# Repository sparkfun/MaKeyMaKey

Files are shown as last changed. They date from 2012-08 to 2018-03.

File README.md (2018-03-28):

**Note: Retired Product**
===========

This product has been retired from our catalog and is no longer for sale. This page is made available for those looking for datasheets and the simply curious. For the latest version of the board manufactured by JoyLabz, check out the [Makey Makey Classic by JoyLabz](https://www.sparkfun.com/products/14478).

---

MaKey MaKey
===========

[MaKey MaKey  
*MaKey MaKey - Standard Kit (WIG-11511)*](https://www.sparkfun.com/products/11511)

Using the MaKey MaKey you can *make* anything into a *key* (get it?) just by connecting a few alligator clips. The MaKey MaKey is an invention kit that tricks your computer into thinking that almost anything is a keyboard. This allows you to hook up all kinds of fun things as an input.

The MaKey MaKey uses high resistance switching to detect when you've made a connection even through materials that aren't very conductive (like leaves, pasta or people). This technique attracts noise on the input, so a moving window averager is used to lowpass the noise. The on-board ATMega32u4 communicates with your computer using the Human Interface Device (HID) protocol which means that it can act like a keyboard or mouse.

Repository Contents
-------------------
* **/Firmware** - Example firmware files
* **/Hardware** - All Eagle design files (.brd, .sch)
* **/Production** - Test bed files and production panel files

Documentation
--------------
* **[Makey Makey Quickstart Guide](https://learn.sparkfun.com/tutorials/makey-makey-quickstart-guide)** - Basic hookup guide for the Makey Makey.
* **[Makey Makey Advanced Guide](https://learn.sparkfun.com/tutorials/makey-makey-advanced-guide)** - Advanced hookup guide for the Makey Makey.

Product Versions
----------------

**[WIG-11511 (Retired)](https://www.sparkfun.com/products/11511) - Standard kit, OEM packaging**  
The standard kit includes the MaKey MaKey HID board, alligator clips, jumper wires, and a Mini-USB cable in OEM packaging.

**[WIG-11519 (Retired)](https://www.sparkfun.com/products/11519) - Deluxe kit, OEM packaging**  
The deluxe kit includes everything found in the standard kit along with an additional pack of alligator clips and a roll of copper wire (all in OEM packaging).

**[RTL-11437 (Retired)](https://www.sparkfun.com/products/11437) - Standard kit, retail packaging**  
This kit contains everything found in the standard kit and comes in retail-ready plastic packaging.

License Information
-------------------
The hardware is released under [Creative Commons ShareAlike 4.0 International](https://creativecommons.org/licenses/by-sa/4.0/).
The code is beerware; if you see me (or any other SparkFun employee) at the local, and you've found our code helpful, please buy us a round!

Distributed as-is; no warranty is given.

The MaKey MaKey is a collaboration with Jay Silver and Eric Rosenbaum. You can find more information about them [here](http://www.makeymakey.com/).

Makey Makey is a registered trademark of JoyLabz LLC.

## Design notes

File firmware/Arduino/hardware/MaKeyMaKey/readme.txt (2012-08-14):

------------------------------------------------------
| MaKey MaKey Arduino Addon (updated August 9, 2012) |
------------------------------------------------------

This Arduino addon for the MaKey MaKey creates an Arduino Board menu option for the MaKey MaKey.

-------------------------------------------------
|         Installing the Arduino Addon          |
-------------------------------------------------

To install this addon, unzip the "MaKeyMaKey" folder into a "hardware" folder withing your Arduino sketchbook. If you don't know where your sketchbook is located, you can find it's location by going to File > Preferences within Arduino.

For Windows XP users, the sketchbook is usually located in your "My Documents/Arduino" directory. So once unzipped, this readme should reside in "My Documents/Arduino/hardware/ProMicro". Windows 7, by default, is something like: C:\Users\<user name>\Arduino\hardware\ProMicro.

Once unzipped, close any Arduino windows and reopen. The following board should be listed in the Tools > Board menu now:
MaKey MaKey

Important: Though the new bootloader is Leonardo-compatible, DO NOT select "Arduino Leonardo" from the Tools > Board menu before uploading code to the MaKey MaKey. Because the MaKey MaKey runs at 8MHz, the sketch uploaded to the board must be configured for that same speed.

-------------------------------------------------
|     Installing the Drivers (Windows only)     |
-------------------------------------------------
Windows users will need to install drivers the first time you connect the MaKey MaKey. Usually a New Hardware Wizard will pop up, you'll need to direct it to the included "Drivers" folder. The driver is "MaKey MaKey.inf".

The included driver should work for MaKey MaKey's with the Sparkfun VID/PID: 0x1B4F/0x2B74 (bootloader) and 0x2B75 (sketch)).

-------------------------------------------------
|            What files are included?           |
-------------------------------------------------

This addon should work with no need to modify files. If you're curious what we've done to the default Arduino files though, read on...

* bootloaders/caterina: This is a slightly modified version of the Caterina bootloader, which is used in the Arduino Leonardo. Defines were modified so the VID and PID were set to SparkFun-specific values (VID: 0x1B4F, PIDs: 0xF100/F101 [get it?!]). To compile this, you'll need to download LUFA, and point the makefile to that directory.

To compile the bootloader for a MaKey MaKey, you must first set F_CPU and PID near the top of the makefile. F_CPU should be 16000000.  PID should be 2B74.

This directory also includes Caterina-makeymakey.hex which is the compiled images of the MaKey MaKey's bootloader. It won't be deleted after running a 'make clean'.

* cores/arduino: This is a mostly unchanged listing of all the core files required by the MaKey MaKey to compile under Arduino. The files with changes are:
	USBCore.cpp: added conditional statement for seting PLLCSR.
	
* variants/makeymakey: This is mostly identical to the Leonardo pins_arduino.h. There is a slight change to the RX and TX LED macros, because the LEDs are biased towards ground, instead of VCC, we had to flop those macros.

* boards.txt: This file is what Arduino looks at when populating its Tools > Board menu.
The "MaKey MaKey" will be added to the Tools > Board menu.

This also defines a few variables such as clock frequency, USB VID and PID, fuses, and bootloader location.

-------------------------------------------------
|         Questions, Comments, Concerns?        |
-------------------------------------------------

Please let us know if this gives you any problems. You can contact our tech support team (techsupport@sparkfun.com), or post a comment on the product page (or even contact me by email, I'd be happy to help) and we'll try to get back to you as quickly as possible.

Have fun!
-Jim (jim at sparkfun.com)

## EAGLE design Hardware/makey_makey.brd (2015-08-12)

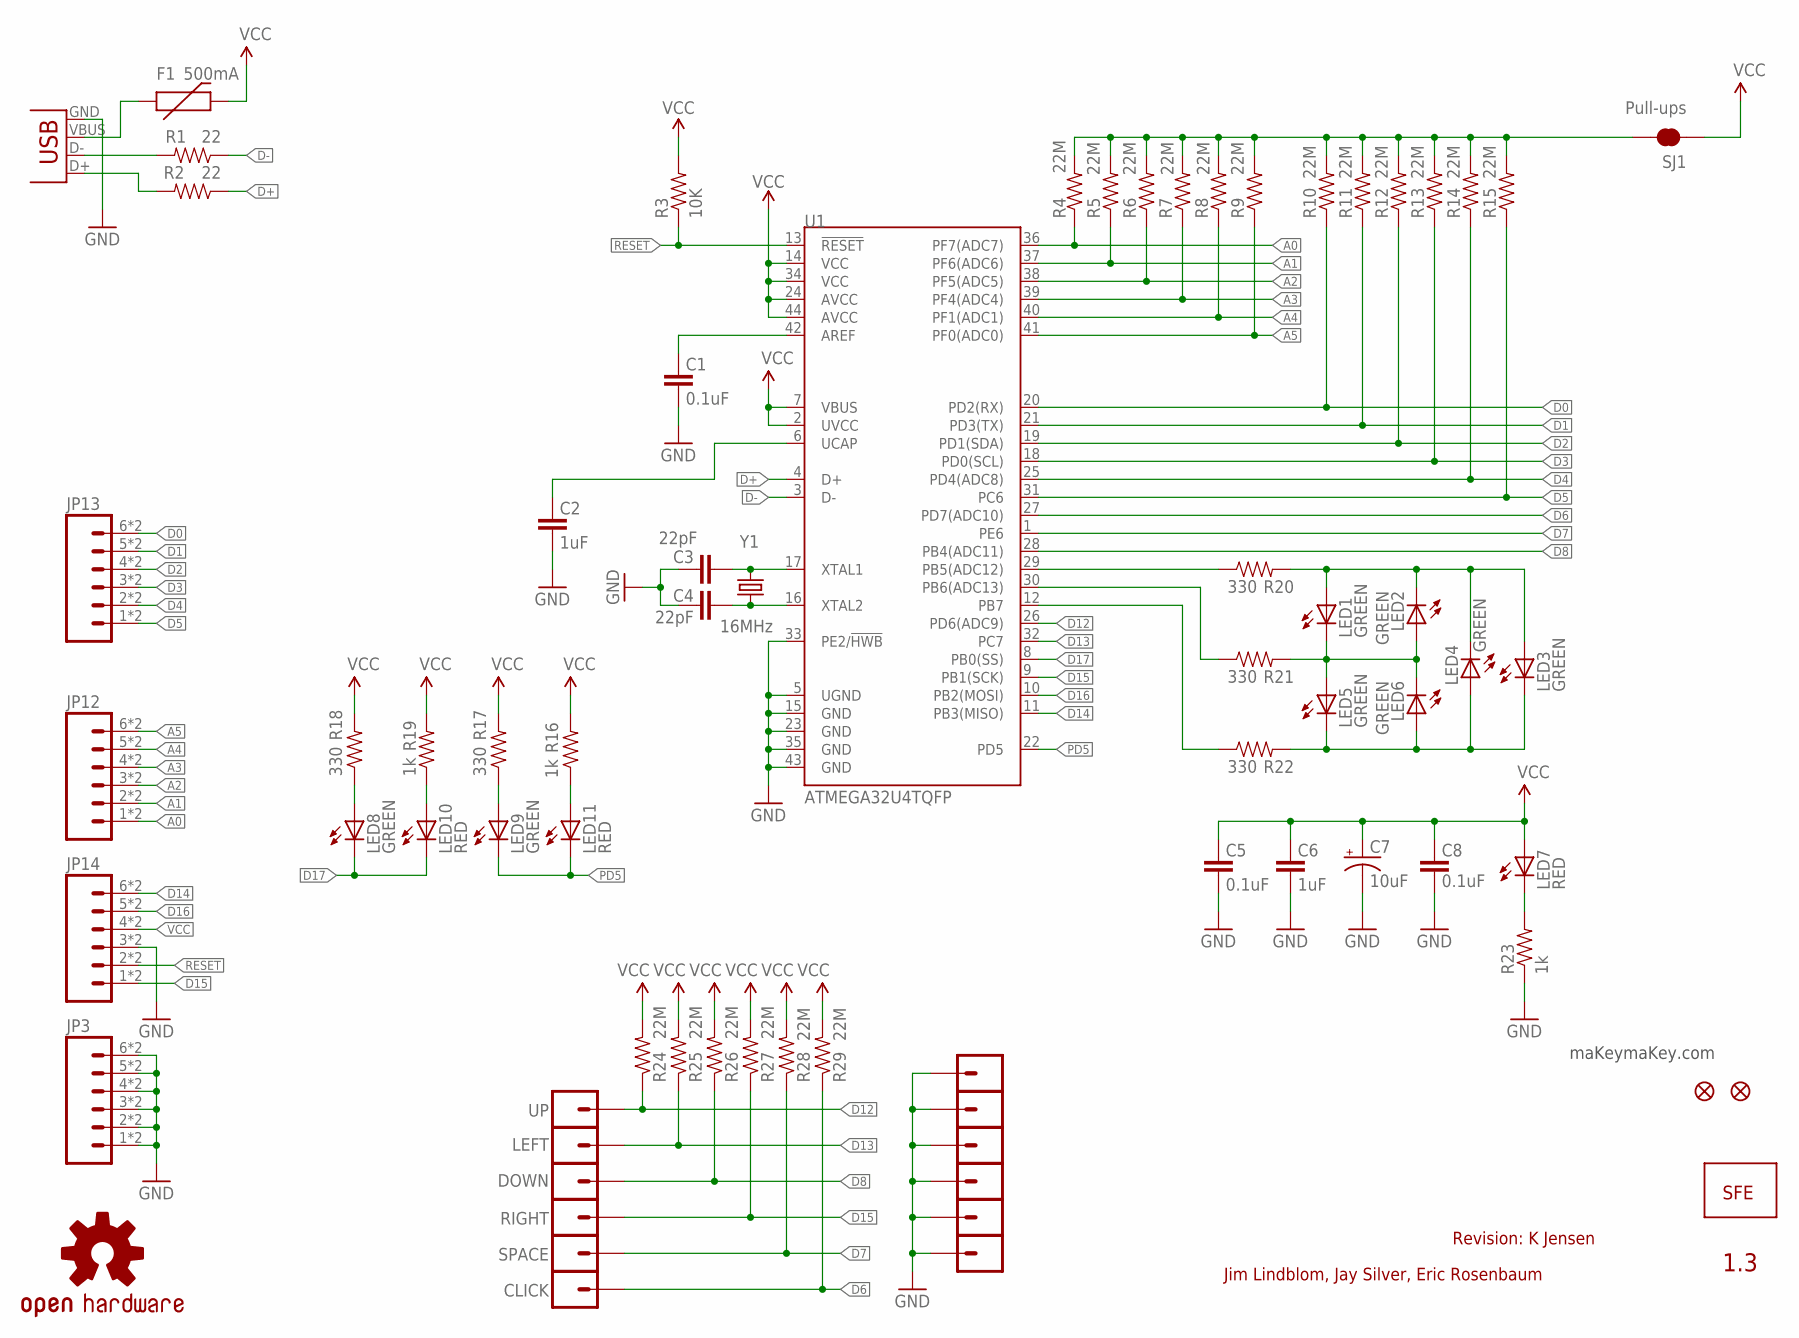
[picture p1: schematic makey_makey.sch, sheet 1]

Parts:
C1, C5, C8: 0.1uF; 0603-CAP
C2, C6: 1uF; 0603-CAP
C3, C4: 22pF; 0603-CAP
C7: 10uF; EIA3216
CLICK: M01ALLIGATOR-3MM; 1X01_ALLIGATOR_3MM
DOWN: M01ALLIGATOR-3MM; 1X01_ALLIGATOR_3MM
F1: 500mA; PTC-1206-WIDE
JP1, JP2: FIDUCIALUFIDUCIAL; MICRO-FIDUCIAL
JP3, JP12, JP13, JP14: M06SMD-STRAIGHT-COMBO; 1X06_SMD_STRAIGHT_COMBO
JP5, JP6, JP7, JP8, JP10, JP11: M01ALLIGATOR-3MM; 1X01_ALLIGATOR_3MM
JP9: LOGO-SFENEW; SFE-NEW-WEBLOGO
LED1, LED2, LED3, LED4, LED5, LED6: GREEN; LED-1206-BOTTOM
LED7, LED10, LED11: RED; LED-0603
LED8, LED9: GREEN; LED-0603
LEFT: M01ALLIGATOR-3MM; 1X01_ALLIGATOR_3MM
R1, R2: 22; 0603-RES
R3: 10K; 0603-RES
R4, R5, R6, R7, R8, R9, R10, R11, R12, R13, R14, R15, R24, R25, R26, R27, R28, R29: 22M; 0603-RES
R16, R19, R23: 1k; 0603-RES
R17, R18, R20, R21, R22: 330; 0603-RES
RIGHT: M01ALLIGATOR-3MM; 1X01_ALLIGATOR_3MM
SJ1: Pull-ups; SJ_2S-TRACE
SPACE: M01ALLIGATOR-3MM; 1X01_ALLIGATOR_3MM
U1: ATMEGA32U4TQFP; TQFP44
U$1: OSHW-LOGOM; OSHW-LOGO-M
UP: M01ALLIGATOR-3MM; 1X01_ALLIGATOR_3MM
X1: USBSMD; USB-MINIB
Y1: 16MHz; CRYSTAL-SMD-5X3

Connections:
A0: JP12.1, JP12.1-2 (1), R4.1, U1.36 (PF7(ADC7))
A1: JP12.2, JP12.2-2 (2), R5.1, U1.37 (PF6(ADC6))
A2: JP12.3, JP12.3-2 (3), R6.1, U1.38 (PF5(ADC5))
A3: JP12.4, JP12.4-2 (4), R7.1, U1.39 (PF4(ADC4))
A4: JP12.5, JP12.5-2 (5), R8.1, U1.40 (PF1(ADC1))
A5: JP12.6, JP12.6-2 (6), R9.1, U1.41 (PF0(ADC0))
AREF: C1.2, U1.42 (AREF)
D0: JP13.6, JP13.6-2 (6), R10.1, U1.20 (PD2(RX))
D1: JP13.5, JP13.5-2 (5), R11.1, U1.21 (PD3(TX))
D2: JP13.4, JP13.4-2 (4), R12.1, U1.19 (PD1(SDA))
D3: JP13.3, JP13.3-2 (3), R13.1, U1.18 (PD0(SCL))
D4: JP13.2, JP13.2-2 (2), R14.1, U1.25 (PD4(ADC8))
D5: JP13.1, JP13.1-2 (1), R15.1, U1.31 (PC6)
D6: CLICK.1@0, CLICK.1@2, R29.1, U1.27 (PD7(ADC10))
D7: R28.1, SPACE.1@0, SPACE.1@2, U1.1 (PE6)
D8: DOWN.1@0, DOWN.1@2, R26.1, U1.28 (PB4(ADC11))
D9: R20.1, U1.29 (PB5(ADC12))
D10: R21.1, U1.30 (PB6(ADC13))
D11: R22.1, U1.12 (PB7)
D12: R24.1, U1.26 (PD6(ADC9)), UP.1@0, UP.1@2
D13: LEFT.1@0, LEFT.1@2, R25.1, U1.32 (PC7)
D14: JP14.6, JP14.6-2 (6), U1.11 (PB3(MISO))
D15: JP14.1, JP14.1-2 (1), R27.1, RIGHT.1@0, RIGHT.1@2, U1.9 (PB1(SCK))
D16: JP14.5, JP14.5-2 (5), U1.10 (PB2(MOSI))
D17: LED8.C, LED10.C, U1.8 (PB0(SS))
D+: R2.1, U1.4 (D+)
D-: R1.1, U1.3 (D-)
GND: C1.1, C2.1, C3.2, C4.2, C5.1, C6.1, C7.C (-), C8.1, JP3.1, JP3.1-2 (1), JP3.2, JP3.2-2 (2), JP3.3, JP3.3-2 (3), JP3.4, JP3.4-2 (4), JP3.5, JP3.5-2 (5), JP3.6, JP3.6-2 (6), JP5.1@0, JP5.1@2, JP6.1@0, JP6.1@2, JP7.1@0, JP7.1@2, JP8.1@0, JP8.1@2, JP10.1@0, JP10.1@2, JP11.1@0, JP11.1@2, JP14.3, JP14.3-2 (3), R23.1, U1.5 (UGND), U1.15 (GND), U1.23 (GND), U1.33 (PE2/!HWB), U1.35 (GND), U1.43 (GND), X1.GND
unnamed: C4.1, U1.16 (XTAL2), Y1.1
unnamed: C3.1, U1.17 (XTAL1), Y1.3 (2)
unnamed: LED8.A, R18.1
unnamed: C2.2, U1.6 (UCAP)
unnamed: F1.1, X1.VBUS
unnamed: R1.2, X1.D-
unnamed: LED7.C, R23.2
unnamed: R2.2, X1.D+
unnamed: LED11.A, R16.1
unnamed: LED10.A, R19.1
unnamed: LED9.A, R17.1
unnamed: LED1.C, LED2.A, LED5.A, LED6.C, R21.2
unnamed: LED1.A, LED2.C, LED3.A, LED4.C, R20.2
unnamed: LED3.C, LED4.A, LED5.C, LED6.A, R22.2
PD5: LED9.C, LED11.C, U1.22 (PD5)
PULL-UP: R4.2, R5.2, R6.2, R7.2, R8.2, R9.2, R10.2, R11.2, R12.2, R13.2, R14.2, R15.2, SJ1.2
RESET: JP14.2, JP14.2-2 (2), R3.1, U1.13 (!RESET)
VCC: C5.2, C6.2, C7.A (+), C8.2, F1.2, JP14.4, JP14.4-2 (4), LED7.A, R3.2, R16.2, R17.2, R18.2, R19.2, R24.2, R25.2, R26.2, R27.2, R28.2, R29.2, SJ1.1, U1.2 (UVCC), U1.7 (VBUS), U1.14 (VCC), U1.24 (AVCC), U1.34 (VCC), U1.44 (AVCC)

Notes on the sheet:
1.3
Jim Lindblom, Jay Silver, Eric Rosenbaum
maKeymaKey.com
Revision: K Jensen

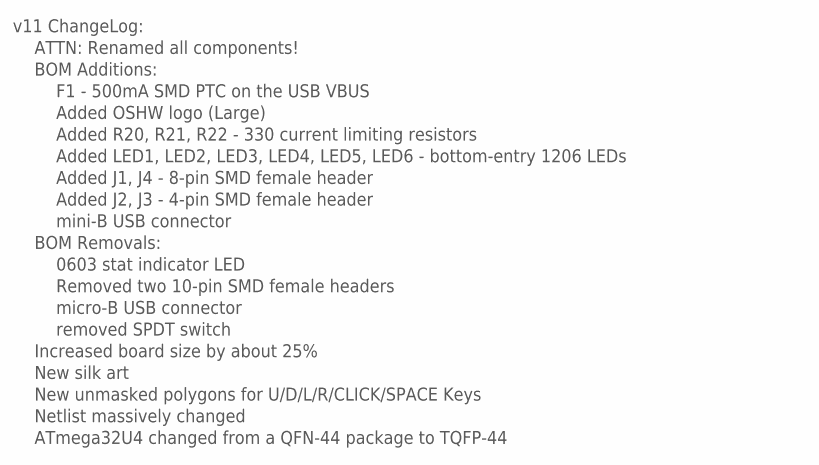
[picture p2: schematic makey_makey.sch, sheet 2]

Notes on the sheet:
v11 ChangeLog:
BOM Additions:
F1 - 500mA SMD PTC on the USB VBUS
Added OSHW logo (Large)
ATTN: Renamed all components!
Added R20, R21, R22 - 330 current limiting resistors
Added LED1, LED2, LED3, LED4, LED5, LED6 - bottom-entry 1206 LEDs
BOM Removals:
0603 stat indicator LED
Increased board size by about 25%
New silk art
Netlist massively changed
Removed two 10-pin SMD female headers
Added J1, J4 - 8-pin SMD female header
Added J2, J3 - 4-pin SMD female header
ATmega32U4 changed from a QFN-44 package to TQFP-44
New unmasked polygons for U/D/L/R/CLICK/SPACE Keys
mini-B USB connector
micro-B USB connector
removed SPDT switch

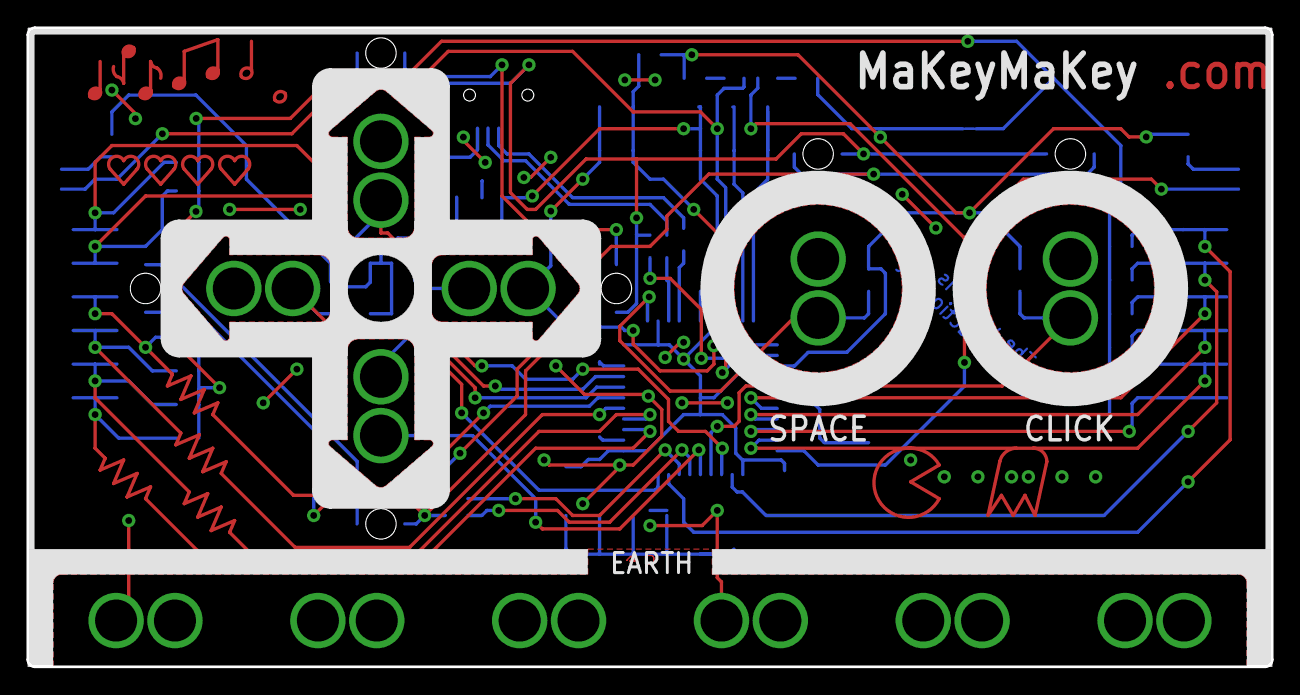
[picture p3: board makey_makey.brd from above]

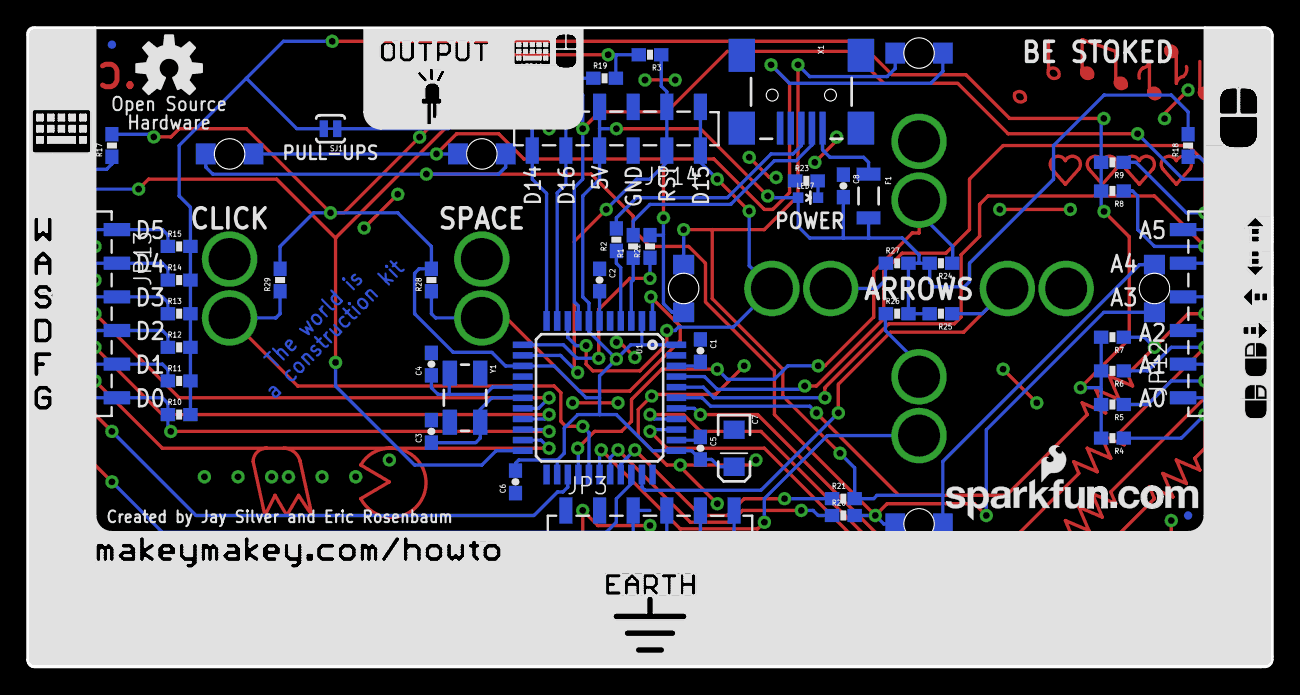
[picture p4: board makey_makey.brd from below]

Board: 2 copper layers, 94.0 x 48.3 mm, 73 parts (63 on the bottom side), 46 nets.

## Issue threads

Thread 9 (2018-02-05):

issue when uploading the code: <Keyboard.h> and <Mouse.h>, no such file or dictionary

Michelleyaooooo, 2018-02-05:
Hi there, I've done all the steps according to this tutorial: https://learn.sparkfun.com/tutorials/makey-makey-advanced-guide

Though when I upload the code, here's the error log:

Arduino: 1.6.5 (Mac OS X), Board: "SparkFun MaKey MaKey"

makey_makey_1_4_2.ino:48:22: fatal error: Keyboard.h: No such file or directory
compilation terminated.
Error compiling.

  This report would have more information with
  "Show verbose output during compilation"
  enabled in File > Preferences.

it doesn't work when remove the #include <Mouse.h> and #include <Keyboard.h>

Thanks in advance!

Michelleyaooooo, 2018-02-05:
when removed those two #include,  the error log shows:

Arduino: 1.6.5 (Mac OS X), Board: "SparkFun MaKey MaKey"

sorry - this program has been built without plugin support
Error compiling.

  This report would have more information with
  "Show verbose output during compilation"
  enabled in File > Preferences.

bboyho, 2018-03-13:
Hi,

Hmm, it worked fine for me but I only tested it on a Windows 10 OS with Arduino IDE v1.8.3. I do not have a Mac available. Try reinstalling your Arduino IDE v1.6.5 or using a different version [ [https://www.arduino.cc/en/Main/OldSoftwareReleases#previous](https://www.arduino.cc/en/Main/OldSoftwareReleases#previous) ].  Also, try to reinstall the board definition [ [https://github.com/sparkfun/Arduino_Boards/](https://github.com/sparkfun/Arduino_Boards/) ].

From the error, I assume that the Arduino IDE is trying to look for the header file but the location of the file is not where it is expecting it to be. You may want to use the library manager: **Sketch > Include LIbrary > Manage Libraries... ** to make sure that the "Keyboard" library is installed.

bboyho, 2018-03-15:
I tested this on a Mac iOS X  and I had issues compiling on Arduino IDE v.1.6.5 but with a different error output:

    Arduino: 1.6.5 (Mac OS X), Board: "SparkFun MaKey MaKey"

    Build options changed, rebuilding all
    In file included from makey_makey.ino:52:0:
    settings.h:20: error: 'KEY_UP_ARROW' was not declared in this scope
       KEY_UP_ARROW,      // up arrow pad
       ^
    settings.h:21: error: 'KEY_DOWN_ARROW' was not declared in this scope
       KEY_DOWN_ARROW,    // down arrow pad
       ^
    settings.h:22: error: 'KEY_LEFT_ARROW' was not declared in this scope
       KEY_LEFT_ARROW,    // left arrow pad
       ^
    settings.h:23: error: 'KEY_RIGHT_ARROW' was not declared in this scope
       KEY_RIGHT_ARROW,   // right arrow pad
       ^
    settings.h:25: error: 'MOUSE_LEFT' was not declared in this scope
       MOUSE_LEFT,        // click button pad
       ^
    settings.h:42: error: 'MOUSE_LEFT' was not declared in this scope
       MOUSE_LEFT,         // pin A1
       ^
    settings.h:43: error: 'MOUSE_RIGHT' was not declared in this scope
       MOUSE_RIGHT         // pin A0
       ^
    makey_makey.ino: In function 'void initializeArduino()':
    makey_makey:184: error: 'Keyboard' only supported on the Arduino Leonardomakey_makey:185: error: 'Mouse' only supported on the Arduino Leonardomakey_makey.ino: In function 'void initializeInputs()':
    makey_makey:229: error: 'MOUSE_LEFT' was not declared in this scope
    makey_makey:229: error: 'MOUSE_RIGHT' was not declared in this scope
    makey_makey.ino: In function 'void updateInputStates()':
    makey_makey:319: error: 'Keyboard' only supported on the Arduino Leonardomakey_makey:334: error: 'Keyboard' only supported on the Arduino Leonardomakey_makey.ino: In function 'void sendMouseButtonEvents()':
    makey_makey:394: error: 'MOUSE_LEFT' was not declared in this scope
    makey_makey:395: error: 'Mouse' only supported on the Arduino Leonardomakey_makey:397: error: 'MOUSE_RIGHT' was not declared in this scope
    makey_makey:398: error: 'Mouse' only supported on the Arduino Leonardomakey_makey:402: error: 'MOUSE_LEFT' was not declared in this scope
    makey_makey:403: error: 'Mouse' only supported on the Arduino Leonardomakey_makey:405: error: 'MOUSE_RIGHT' was not declared in this scope
    makey_makey:406: error: 'Mouse' only supported on the Arduino Leonardomakey_makey.ino: In function 'void sendMouseMovementEvents()':
    makey_makey:493: error: 'Mouse' only supported on the Arduino Leonardo'KEY_UP_ARROW' was not declared in this scope

      This report would have more information with
      "Show verbose output during compilation"
      enabled in File > Preferences.

When testing on v1.8+, I had no issues compiling with the latest board definition. This may have something to do with the way the Arduino IDE v1.6.5 paths were setup, the new board add on specifications [ [https://github.com/arduino/Arduino/wiki/Arduino-IDE-1.5:-Library-specification](https://github.com/arduino/Arduino/wiki/Arduino-IDE-1.5:-Library-specification) ], or the configuration of the Mac iOS X that I was testing on. Since the ATmega32U4-Based Makey Makey is retired, the best solution would be to update your IDE version, update your board add-on, or try on a different computer.

bboyho, 2018-03-28:
Since the Makey Makey w/ Atmega32U4 has been retired in SparkFun's catalog, I will be closing this issue. If you have further issues, you may want to check out the following resources if you still have issues compiling:

* [SparkFun Technical Support](https://www.sparkfun.com/technical_assistance)
* [SparkFun Forums](https://forum.sparkfun.com/)
* [Arduino.cc Forums](https://forum.arduino.cc/)

Closed 2018-03-28.

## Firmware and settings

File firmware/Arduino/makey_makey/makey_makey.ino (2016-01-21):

/*
 ************************************************
 ************** MAKEY MAKEY *********************
 ************************************************
 
 /////////////////////////////////////////////////
 /////////////HOW TO EDIT THE KEYS ///////////////
 /////////////////////////////////////////////////
 - Edit keys in the settings.h file
 - that file should be open in a tab above (in Arduino IDE)
 - more instructions are in that file
 
 //////////////////////////////////////////////////
 ///////// MaKey MaKey FIRMWARE v1.4.1 ////////////
 //////////////////////////////////////////////////
 by: Eric Rosenbaum, Jay Silver, and Jim Lindblom
 MIT Media Lab & Sparkfun
 start date: 2/16/2012 
 current release: 7/5/2012
 */

/////////////////////////
// DEBUG DEFINITIONS ////               
/////////////////////////
//#define DEBUG
//#define DEBUG2 
//#define DEBUG3 
//#define DEBUG_TIMING
//#define DEBUG_MOUSE
//#define DEBUG_TIMING2

////////////////////////
// DEFINED CONSTANTS////
////////////////////////

#define BUFFER_LENGTH    3     // 3 bytes gives us 24 samples
#define NUM_INPUTS       18    // 6 on the front + 12 on the back
//#define TARGET_LOOP_TIME 694   // (1/60 seconds) / 24 samples = 694 microseconds per sample 
//#define TARGET_LOOP_TIME 758  // (1/55 seconds) / 24 samples = 758 microseconds per sample 
#define TARGET_LOOP_TIME 744  // (1/56 seconds) / 24 samples = 744 microseconds per sample 

// id numbers for mouse movement inputs (used in settings.h)
#define MOUSE_MOVE_UP       -1 
#define MOUSE_MOVE_DOWN     -2
#define MOUSE_MOVE_LEFT     -3
#define MOUSE_MOVE_RIGHT    -4

#if (ARDUINO > 10605)
  #include <Keyboard.h>
  #include <Mouse.h>
#endif
#include "settings.h"

/////////////////////////
// STRUCT ///////////////
/////////////////////////
typedef struct {
  byte pinNumber;
  int keyCode;
  byte measurementBuffer[BUFFER_LENGTH]; 
  boolean oldestMeasurement;
  byte bufferSum;
  boolean pressed;
  boolean prevPressed;
  boolean isMouseMotion;
  boolean isMouseButton;
  boolean isKey;
} 
MakeyMakeyInput;

MakeyMakeyInput inputs[NUM_INPUTS];

///////////////////////////////////
// VARIABLES //////////////////////
///////////////////////////////////
int bufferIndex = 0;
byte byteCounter = 0;
byte bitCounter = 0;
int mouseMovementCounter = 0; // for sending mouse movement events at a slower interval

int pressThreshold;
int releaseThreshold;
boolean inputChanged;

int mouseHoldCount[NUM_INPUTS]; // used to store mouse movement hold data

// Pin Numbers
// input pin numbers for kickstarter production board
int pinNumbers[NUM_INPUTS] = {
  12, 8, 13, 15, 7, 6,     // top of makey makey board
  5, 4, 3, 2, 1, 0,        // left side of female header, KEYBOARD
  23, 22, 21, 20, 19, 18   // right side of female header, MOUSE
};

// input status LED pin numbers
const int inputLED_a = 9;
const int inputLED_b = 10;
const int inputLED_c = 11;
const int outputK = 14;
const int outputM = 16;
byte ledCycleCounter = 0;

// timing
int loopTime = 0;
int prevTime = 0;
int loopCounter = 0;


///////////////////////////
// FUNCTIONS //////////////
///////////////////////////
void initializeArduino();
void initializeInputs();
void updateMeasurementBuffers();
void updateBufferSums();
void updateBufferIndex();
void updateInputStates();
void sendMouseButtonEvents();
void sendMouseMovementEvents();
void addDelay();
void cycleLEDs();
void danceLeds();
void updateOutLEDs();

//////////////////////
// SETUP /////////////
//////////////////////
void setup() 
{
  initializeArduino();
  initializeInputs();
  danceLeds();
}

////////////////////
// MAIN LOOP ///////
////////////////////
void loop() 
{
  updateMeasurementBuffers();
  updateBufferSums();
  updateBufferIndex();
  updateInputStates();
  sendMouseButtonEvents();
  sendMouseMovementEvents();
  cycleLEDs();
  updateOutLEDs();
  addDelay();
}

//////////////////////////
// INITIALIZE ARDUINO
//////////////////////////
void initializeArduino() {
#ifdef DEBUG
  Serial.begin(9600);  // Serial for debugging
#endif

  /* Set up input pins 
   DEactivate the internal pull-ups, since we're using external resistors */
  for (int i=0; i<NUM_INPUTS; i++)
  {
    pinMode(pinNumbers[i], INPUT);
    digitalWrite(pinNumbers[i], LOW);
  }

  pinMode(inputLED_a, INPUT);
  pinMode(inputLED_b, INPUT);
  pinMode(inputLED_c, INPUT);
  digitalWrite(inputLED_a, LOW);
  digitalWrite(inputLED_b, LOW);
  digitalWrite(inputLED_c, LOW);

  pinMode(outputK, OUTPUT);
  pinMode(outputM, OUTPUT);
  digitalWrite(outputK, LOW);
  digitalWrite(outputM, LOW);


#ifdef DEBUG
  delay(4000); // allow us time to reprogram in case things are freaking out
#endif

  Keyboard.begin();
  Mouse.begin();
}

///////////////////////////
// INITIALIZE INPUTS
///////////////////////////
void initializeInputs() {

  float thresholdPerc = SWITCH_THRESHOLD_OFFSET_PERC;
  float thresholdCenterBias = SWITCH_THRESHOLD_CENTER_BIAS/50.0;
  float pressThresholdAmount = (BUFFER_LENGTH * 8) * (thresholdPerc / 100.0);
  float thresholdCenter = ( (BUFFER_LENGTH * 8) / 2.0 ) * (thresholdCenterBias);
  pressThreshold = int(thresholdCenter + pressThresholdAmount);
  releaseThreshold = int(thresholdCenter - pressThresholdAmount);

#ifdef DEBUG
  Serial.println(pressThreshold);
  Serial.println(releaseThreshold);
#endif

  for (int i=0; i<NUM_INPUTS; i++) {
    inputs[i].pinNumber = pinNumbers[i];
    inputs[i].keyCode = keyCodes[i];

    for (int j=0; j<BUFFER_LENGTH; j++) {
      inputs[i].measurementBuffer[j] = 0;
    }
    inputs[i].oldestMeasurement = 0;
    inputs[i].bufferSum = 0;

    inputs[i].pressed = false;
    inputs[i].prevPressed = false;

    inputs[i].isMouseMotion = false;
    inputs[i].isMouseButton = false;
    inputs[i].isKey = false;

    if (inputs[i].keyCode < 0) {
#ifdef DEBUG_MOUSE
      Serial.println("GOT IT");  
#endif

      inputs[i].isMouseMotion = true;
    } 
    else if ((inputs[i].keyCode == MOUSE_LEFT) || (inputs[i].keyCode == MOUSE_RIGHT)) {
      inputs[i].isMouseButton = true;
    } 
    else {
      inputs[i].isKey = true;
    }
#ifdef DEBUG
    Serial.println(i);
#endif

  }
}


//////////////////////////////
// UPDATE MEASUREMENT BUFFERS
//////////////////////////////
void updateMeasurementBuffers() {

  for (int i=0; i<NUM_INPUTS; i++) {

    // store the oldest measurement, which is the one at the current index,
    // before we update it to the new one 
    // we use oldest measurement in updateBufferSums
    byte currentByte = inputs[i].measurementBuffer[byteCounter];
    inputs[i].oldestMeasurement = (currentByte >> bitCounter) & 0x01; 

    // make the new measurement
    boolean newMeasurement = digitalRead(inputs[i].pinNumber);

    // invert so that true means the switch is closed
    newMeasurement = !newMeasurement; 

    // store it    
    if (newMeasurement) {
      currentByte |= (1<<bitCounter);
    } 
    else {
      currentByte &= ~(1<<bitCounter);
    }
    inputs[i].measurementBuffer[byteCounter] = currentByte;
  }
}

///////////////////////////
// UPDATE BUFFER SUMS
///////////////////////////
void updateBufferSums() {

  // the bufferSum is a running tally of the entire measurementBuffer
  // add the new measurement and subtract the old one

  for (int i=0; i<NUM_INPUTS; i++) {
    byte currentByte = inputs[i].measurementBuffer[byteCounter];
    boolean currentMeasurement = (currentByte >> bitCounter) & 0x01; 
    if (currentMeasurement) {
      inputs[i].bufferSum++;
    }
    if (inputs[i].oldestMeasurement) {
      inputs[i].bufferSum--;
    }
  }  
}

///////////////////////////
// UPDATE BUFFER INDEX
///////////////////////////
void updateBufferIndex() {
  bitCounter++;
  if (bitCounter == 8) {
    bitCounter = 0;
    byteCounter++;
    if (byteCounter == BUFFER_LENGTH) {
      byteCounter = 0;
    }
  }
}

///////////////////////////
// UPDATE INPUT STATES
///////////////////////////
void updateInputStates() {
  inputChanged = false;
  for (int i=0; i<NUM_INPUTS; i++) {
    inputs[i].prevPressed = inputs[i].pressed; // store previous pressed state (only used for mouse buttons)
    if (inputs[i].pressed) {
      if (inputs[i].bufferSum < releaseThreshold) {  
        inputChanged = true;
        inputs[i].pressed = false;
        if (inputs[i].isKey) {
          Keyboard.release(inputs[i].keyCode);
        }
        if (inputs[i].isMouseMotion) {  
          mouseHoldCount[i] = 0;  // input becomes released, reset mouse hold
        }
      }
      else if (inputs[i].isMouseMotion) {  
        mouseHoldCount[i]++; // input remains pressed, increment mouse hold
      }
    } 
    else if (!inputs[i].pressed) {
      if (inputs[i].bufferSum > pressThreshold) {  // input becomes pressed
        inputChanged = true;
        inputs[i].pressed = true; 
        if (inputs[i].isKey) {
          Keyboard.press(inputs[i].keyCode);
        }
      }
    }
  }
#ifdef DEBUG3
  if (inputChanged) {
    Serial.println("change");
  }
#endif
}

/*
///////////////////////////
 // SEND KEY EVENTS (obsolete, used in versions with pro micro bootloader)
 ///////////////////////////
 void sendKeyEvents() {
 if (inputChanged) {
 KeyReport report = {
 0                                                        };
 for (int i=0; i<6; i++) {
 report.keys[i] = 0;
 } 
 int count = 0;
 for (int i=0; i<NUM_INPUTS; i++) {
 if (inputs[i].pressed && (count < 6)) {
 report.keys[count] = inputs[i].keyCode;
 
 #ifdef DEBUG3
 Serial.println(report.keys[count]);
 #endif
 
 count++;        
 }
 }
 if (count > 0) {
 report.modifiers = 0x00;
 report.reserved = 1;
 Keyboard.sendReport(&report);
 } 
 else {
 report.modifiers = 0x00;
 report.reserved = 0;
 Keyboard.sendReport(&report);
 }      
 } 
 else {
 // might need a delay here to compensate for the time it takes to send keyreport
 }
 }
 */

/////////////////////////////
// SEND MOUSE BUTTON EVENTS 
/////////////////////////////
void sendMouseButtonEvents() {
  if (inputChanged) {
    for (int i=0; i<NUM_INPUTS; i++) {
      if (inputs[i].isMouseButton) {
        if (inputs[i].pressed) {
          if (inputs[i].keyCode == MOUSE_LEFT) {
            Mouse.press(MOUSE_LEFT);
          } 
          if (inputs[i].keyCode == MOUSE_RIGHT) {
            Mouse.press(MOUSE_RIGHT);
          } 
        } 
        else if (inputs[i].prevPressed) {
          if (inputs[i].keyCode == MOUSE_LEFT) {
            Mouse.release(MOUSE_LEFT);
          } 
          if (inputs[i].keyCode == MOUSE_RIGHT) {
            Mouse.release(MOUSE_RIGHT);
          }           
        }
      }
    }
  }
}

//////////////////////////////
// SEND MOUSE MOVEMENT EVENTS
//////////////////////////////
void sendMouseMovementEvents() {
  byte right = 0;
  byte left = 0;
  byte down = 0;
  byte up = 0;
  byte horizmotion = 0;
  byte vertmotion = 0;

  mouseMovementCounter++;
  mouseMovementCounter %= MOUSE_MOTION_UPDATE_INTERVAL;
  if (mouseMovementCounter == 0) {
    for (int i=0; i<NUM_INPUTS; i++) {
#ifdef DEBUG_MOUSE
      //  Serial.println(inputs[i].isMouseMotion);  
#endif

      if (inputs[i].isMouseMotion) {
        if (inputs[i].pressed) {
          if (inputs[i].keyCode == MOUSE_MOVE_UP) {
            // JL Changes (x4): now update to 1 + a hold factor, constrained between 1 and mouse max movement speed
            up=constrain(1+mouseHoldCount[i]/MOUSE_RAMP_SCALE, 1, MOUSE_MAX_PIXELS);
          }  
          if (inputs[i].keyCode == MOUSE_MOVE_DOWN) {
            down=constrain(1+mouseHoldCount[i]/MOUSE_RAMP_SCALE, 1, MOUSE_MAX_PIXELS);
          }  
          if (inputs[i].keyCode == MOUSE_MOVE_LEFT) {
            left=constrain(1+mouseHoldCount[i]/MOUSE_RAMP_SCALE, 1, MOUSE_MAX_PIXELS);
          }  
          if (inputs[i].keyCode == MOUSE_MOVE_RIGHT) {
            right=constrain(1+mouseHoldCount[i]/MOUSE_RAMP_SCALE, 1, MOUSE_MAX_PIXELS);
          }  
        }
      }
    }

    // diagonal scrolling and left/right cancellation
    if(left > 0)
    {
      if(right > 0)
      {
        horizmotion = 0; // cancel horizontal motion because left and right are both pushed
      }
      else
      {
        horizmotion = -left; // left yes, right no
      }
    }
    else
    {
      if(right > 0)
      {
        horizmotion = right; // right yes, left no
      }
    }

    if(down > 0)
    {
      if(up > 0)
      {
        vertmotion = 0; // cancel vertical motion because up and down are both pushed
      }
      else
      {
        vertmotion = down; // down yes, up no
      }
    }
    else
    {
      if (up > 0)
      {
        vertmotion = -up; // up yes, down no
      }
    }
    // now move the mouse
    if( !((horizmotion == 0) && (vertmotion==0)) )
    {
      Mouse.move(horizmotion * PIXELS_PER_MOUSE_STEP, vertmotion * PIXELS_PER_MOUSE_STEP);
    }
  }
}

///////////////////////////
// ADD DELAY
///////////////////////////
void addDelay() {

  loopTime = micros() - prevTime;
  if (loopTime < TARGET_LOOP_TIME) {
    int wait = TARGET_LOOP_TIME - loopTime;
    delayMicroseconds(wait);
  }

  prevTime = micros();

#ifdef DEBUG_TIMING
  if (loopCounter == 0) {
    int t = micros()-prevTime;
    Serial.println(t);
  }
  loopCounter++;
  loopCounter %= 999;
#endif

}

///////////////////////////
// CYCLE LEDS
///////////////////////////
void cycleLEDs() {
  pinMode(inputLED_a, INPUT);
  pinMode(inputLED_b, INPUT);
  pinMode(inputLED_c, INPUT);
  digitalWrite(inputLED_a, LOW);
  digitalWrite(inputLED_b, LOW);
  digitalWrite(inputLED_c, LOW);

  ledCycleCounter++;
  ledCycleCounter %= 6;

  if ((ledCycleCounter == 0) && inputs[0].pressed) {
    pinMode(inputLED_a, INPUT);
    digitalWrite(inputLED_a, LOW);
    pinMode(inputLED_b, OUTPUT);
    digitalWrite(inputLED_b, HIGH);
    pinMode(inputLED_c, OUTPUT);
    digitalWrite(inputLED_c, LOW);
  }
  if ((ledCycleCounter == 1) && inputs[1].pressed) {
    pinMode(inputLED_a, OUTPUT);
    digitalWrite(inputLED_a, HIGH);
    pinMode(inputLED_b, OUTPUT);
    digitalWrite(inputLED_b, LOW);
    pinMode(inputLED_c, INPUT);
    digitalWrite(inputLED_c, LOW);

  }
  if ((ledCycleCounter == 2) && inputs[2].pressed) {
    pinMode(inputLED_a, OUTPUT);
    digitalWrite(inputLED_a, LOW);
    pinMode(inputLED_b, OUTPUT);
    digitalWrite(inputLED_b, HIGH);
    pinMode(inputLED_c, INPUT);
    digitalWrite(inputLED_c, LOW);
  }
  if ((ledCycleCounter == 3) && inputs[3].pressed) {
    pinMode(inputLED_a, INPUT);
    digitalWrite(inputLED_a, LOW);
    pinMode(inputLED_b, OUTPUT);
    digitalWrite(inputLED_b, LOW);
    pinMode(inputLED_c, OUTPUT);
    digitalWrite(inputLED_c, HIGH);
  }
  if ((ledCycleCounter == 4) && inputs[4].pressed) {
    pinMode(inputLED_a, OUTPUT);
    digitalWrite(inputLED_a, LOW);
    pinMode(inputLED_b, INPUT);
    digitalWrite(inputLED_b, LOW);
    pinMode(inputLED_c, OUTPUT);
    digitalWrite(inputLED_c, HIGH);
  }
  if ((ledCycleCounter == 5) && inputs[5].pressed) {
    pinMode(inputLED_a, OUTPUT);
    digitalWrite(inputLED_a, HIGH);
    pinMode(inputLED_b, INPUT);
    digitalWrite(inputLED_b, LOW);
    pinMode(inputLED_c, OUTPUT);
    digitalWrite(inputLED_c, LOW);
  }

}

///////////////////////////
// DANCE LEDS
///////////////////////////
void danceLeds()
{
  int delayTime = 50;
  int delayTime2 = 100;

  // CIRCLE
  for(int i=0; i<4; i++)
  {
    // UP
    pinMode(inputLED_a, INPUT);
    digitalWrite(inputLED_a, LOW);
    pinMode(inputLED_b, OUTPUT);
    digitalWrite(inputLED_b, HIGH);
    pinMode(inputLED_c, OUTPUT);
    digitalWrite(inputLED_c, LOW);
    delay(delayTime);

    //RIGHT
    pinMode(inputLED_a, INPUT);
    digitalWrite(inputLED_a, LOW);
    pinMode(inputLED_b, OUTPUT);
    digitalWrite(inputLED_b, LOW);
    pinMode(inputLED_c, OUTPUT);
    digitalWrite(inputLED_c, HIGH);
    delay(delayTime);


    // DOWN
    pinMode(inputLED_a, OUTPUT);
    digitalWrite(inputLED_a, HIGH);
    pinMode(inputLED_b, OUTPUT);
    digitalWrite(inputLED_b, LOW);
    pinMode(inputLED_c, INPUT);
    digitalWrite(inputLED_c, LOW);
    delay(delayTime);

    // LEFT
    pinMode(inputLED_a, OUTPUT);
    digitalWrite(inputLED_a, LOW);
    pinMode(inputLED_b, OUTPUT);    
    digitalWrite(inputLED_b, HIGH);
    pinMode(inputLED_c, INPUT);
    digitalWrite(inputLED_c, LOW);
    delay(delayTime);    
  }    

  // WIGGLE
  for(int i=0; i<4; i++)
  {
    // SPACE
    pinMode(inputLED_a, OUTPUT);
    digitalWrite(inputLED_a, HIGH);
    pinMode(inputLED_b, INPUT);
    digitalWrite(inputLED_b, LOW);
    pinMode(inputLED_c, OUTPUT);
    digitalWrite(inputLED_c, LOW);
    delay(delayTime2);    

    // CLICK
    pinMode(inputLED_a, OUTPUT);
    digitalWrite(inputLED_a, LOW);
    pinMode(inputLED_b, INPUT);
    digitalWrite(inputLED_b, LOW);
    pinMode(inputLED_c, OUTPUT);
    digitalWrite(inputLED_c, HIGH);
    delay(delayTime2);    
  }
}

void updateOutLEDs()
{
  boolean keyPressed = 0;
  boolean mousePressed = 0;

  for (int i=0; i<NUM_INPUTS; i++)
  {
    if (inputs[i].pressed)
    {
      if (inputs[i].isKey)
      {
        keyPressed = 1;
#ifdef DEBUG
        Serial.print("Key ");
        Serial.print(i);
        Serial.println(" pressed");
#endif
      }
      else
      {
        mousePressed = 1;
      }
    }
  }

  if (keyPressed)
  {
    digitalWrite(outputK, HIGH);
    TXLED1;
  }
  else
  {
    digitalWrite(outputK, LOW);
    TXLED0;
  }

  if (mousePressed)
  {
    digitalWrite(outputM, HIGH);
    RXLED1;
  }
  else
  {
    digitalWrite(outputM, LOW);
    RXLED0;
  }
}

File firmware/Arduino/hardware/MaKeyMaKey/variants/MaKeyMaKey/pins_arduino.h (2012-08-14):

/*
  pins_arduino.h - Pin definition functions for Arduino
  Part of Arduino - http://www.arduino.cc/

  Copyright (c) 2007 David A. Mellis

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
  $Id: wiring.h 249 2007-02-03 16:52:51Z mellis $
*/

#ifndef Pins_Arduino_h
#define Pins_Arduino_h

#include <avr/pgmspace.h>

#define TX_RX_LED_INIT	DDRD |= (1<<5), DDRB |= (1<<0)
#define TXLED0			PORTD |= (1<<5)
#define TXLED1			PORTD &= ~(1<<5)
#define RXLED0			PORTB |= (1<<0)
#define RXLED1			PORTB &= ~(1<<0)

static const uint8_t SDA = 2;
static const uint8_t SCL = 3;

// Map SPI port to 'new' pins D14..D17
static const uint8_t SS   = 17;
static const uint8_t MOSI = 16;
static const uint8_t MISO = 14;
static const uint8_t SCK  = 15;

// Mapping of analog pins as digital I/O
// A6-A11 share with digital pins
static const uint8_t A0 = 18;
static const uint8_t A1 = 19;
static const uint8_t A2 = 20;
static const uint8_t A3 = 21;
static const uint8_t A4 = 22;
static const uint8_t A5 = 23;
static const uint8_t A6 = 24;	// D4
static const uint8_t A7 = 25;	// D6
static const uint8_t A8 = 26;	// D8
static const uint8_t A9 = 27;	// D9
static const uint8_t A10 = 28;	// D10
static const uint8_t A11 = 29;	// D12

#define digitalPinToPCICR(p)    ((((p) >= 8 && (p) <= 11) || ((p) >= 14 && (p) <= 17) || ((p) >= A8 && (p) <= A10)) ? (&PCICR) : ((uint8_t *)0))
#define digitalPinToPCICRbit(p) 0
#define digitalPinToPCMSK(p)    ((((p) >= 8 && (p) <= 11) || ((p) >= 14 && (p) <= 17) || ((p) >= A8 && (p) <= A10)) ? (&PCMSK0) : ((uint8_t *)0))
#define digitalPinToPCMSKbit(p) ( ((p) >= 8 && (p) <= 11) ? (p) - 4 : ((p) == 14 ? 3 : ((p) == 15 ? 1 : ((p) == 16 ? 2 : ((p) == 17 ? 0 : (p - A8 + 4))))))

//	__AVR_ATmega32U4__ has an unusual mapping of pins to channels
extern const uint8_t PROGMEM analog_pin_to_channel_PGM[];
#define analogPinToChannel(P)  ( pgm_read_byte( analog_pin_to_channel_PGM + (P) ) )

#ifdef ARDUINO_MAIN

// On the Arduino board, digital pins are also used
// for the analog output (software PWM).  Analog input
// pins are a separate set.

// ATMEL ATMEGA32U4 / ARDUINO LEONARDO
//
// D0				PD2					RXD1/INT2
// D1				PD3					TXD1/INT3
// D2				PD1		SDA			SDA/INT1
// D3#				PD0		PWM8/SCL	OC0B/SCL/INT0
// D4		A6		PD4					ADC8
// D5#				PC6		???			OC3A/#OC4A
// D6#		A7		PD7		FastPWM		#OC4D/ADC10
// D7				PE6					INT6/AIN0
//
// D8		A8		PB4					ADC11/PCINT4
// D9#		A9		PB5		PWM16		OC1A/#OC4B/ADC12/PCINT5
// D10#		A10		PB6		PWM16		OC1B/0c4B/ADC13/PCINT6
// D11#				PB7		PWM8/16		0C0A/OC1C/#RTS/PCINT7
// D12		A11		PD6					T1/#OC4D/ADC9
// D13#				PC7		PWM10		CLK0/OC4A
//
// A0		D18		PF7					ADC7
// A1		D19		PF6					ADC6
// A2		D20 	PF5					ADC5
// A3		D21 	PF4					ADC4
// A4		D22		PF1					ADC1
// A5		D23 	PF0					ADC0
//
// New pins D14..D17 to map SPI port to digital pins
//
// MISO		D14		PB3					MISO,PCINT3
// SCK		D15		PB1					SCK,PCINT1
// MOSI		D16		PB2					MOSI,PCINT2
// SS		D17		PB0					RXLED,SS/PCINT0
//
// TXLED			PD5
// RXLED		    PB0
// HWB				PE2					HWB

// these arrays map port names (e.g. port B) to the
// appropriate addresses for various functions (e.g. reading
// and writing)
const uint16_t PROGMEM port_to_mode_PGM[] = {
	NOT_A_PORT,
	NOT_A_PORT,
	(uint16_t) &DDRB,
	(uint16_t) &DDRC,
	(uint16_t) &DDRD,
	(uint16_t) &DDRE,
	(uint16_t) &DDRF,
};

const uint16_t PROGMEM port_to_output_PGM[] = {
	NOT_A_PORT,
	NOT_A_PORT,
	(uint16_t) &PORTB,
	(uint16_t) &PORTC,
	(uint16_t) &PORTD,
	(uint16_t) &PORTE,
	(uint16_t) &PORTF,
};

const uint16_t PROGMEM port_to_input_PGM[] = {
	NOT_A_PORT,
	NOT_A_PORT,
	(uint16_t) &PINB,
	(uint16_t) &PINC,
	(uint16_t) &PIND,
	(uint16_t) &PINE,
	(uint16_t) &PINF,
};

const uint8_t PROGMEM digital_pin_to_port_PGM[30] = {
	PD, // D0 - PD2
	PD,	// D1 - PD3
	PD, // D2 - PD1
	PD,	// D3 - PD0
	PD,	// D4 - PD4
	PC, // D5 - PC6
	PD, // D6 - PD7
	PE, // D7 - PE6
	
	PB, // D8 - PB4
	PB,	// D9 - PB5
	PB, // D10 - PB6
	PB,	// D11 - PB7
	PD, // D12 - PD6
	PC, // D13 - PC7
	
	PB,	// D14 - MISO - PB3
	PB,	// D15 - SCK - PB1
	PB,	// D16 - MOSI - PB2
	PB,	// D17 - SS - PB0
	
	PF,	// D18 - A0 - PF7
	PF, // D19 - A1 - PF6
	PF, // D20 - A2 - PF5
	PF, // D21 - A3 - PF4
	PF, // D22 - A4 - PF1
	PF, // D23 - A5 - PF0
	
	PD, // D24 / D4 - A6 - PD4
	PD, // D25 / D6 - A7 - PD7
	PB, // D26 / D8 - A8 - PB4
	PB, // D27 / D9 - A9 - PB5
	PB, // D28 / D10 - A10 - PB6
	PD, // D29 / D12 - A11 - PD6
};
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

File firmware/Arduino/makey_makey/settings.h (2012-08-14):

#include "Arduino.h"

/*
/////////////////////////////////////////////////////////////////////////
// KEY MAPPINGS: WHICH KEY MAPS TO WHICH PIN ON THE MAKEY MAKEY BOARD? //
/////////////////////////////////////////////////////////////////////////
  
  - edit the keyCodes array below to change the keys sent by the MaKey MaKey for each input
  - the comments tell you which input sends that key (for example, by default 'w' is sent by pin D5)
  - change the keys by replacing them. for example, you can replace 'w' with any other individual letter,
    number, or symbol on your keyboard
  - you can also use codes for other keys such as modifier and function keys (see the
    the list of additional key codes at the bottom of this file)

*/

int keyCodes[NUM_INPUTS] = {
  // top side of the makey makey board
 
  KEY_UP_ARROW,      // up arrow pad
  KEY_DOWN_ARROW,    // down arrow pad
  KEY_LEFT_ARROW,    // left arrow pad
  KEY_RIGHT_ARROW,   // right arrow pad
  ' ',               // space button pad
  MOUSE_LEFT,        // click button pad
  
  // female header on the back left side
  
  'w',                // pin D5
  'a',                // pin D4
  's',                // pin D3
  'd',                // pin D2
  'f',                // pin D1
  'g',                // pin D0
  
  // female header on the back right side
  
  MOUSE_MOVE_UP,      // pin A5
  MOUSE_MOVE_DOWN,    // pin A4
  MOUSE_MOVE_LEFT,    // pin A3
  MOUSE_MOVE_RIGHT,   // pin A2
  MOUSE_LEFT,         // pin A1
  MOUSE_RIGHT         // pin A0
};

///////////////////////////
// NOISE CANCELLATION /////
///////////////////////////
#define SWITCH_THRESHOLD_OFFSET_PERC  5    // number between 1 and 49
                                           // larger value protects better against noise oscillations, but makes it harder to press and release
                                           // recommended values are between 2 and 20
                                           // default value is 5

#define SWITCH_THRESHOLD_CENTER_BIAS 55   // number between 1 and 99
                                          // larger value makes it easier to "release" keys, but harder to "press"
                                          // smaller value makes it easier to "press" keys, but harder to "release"
                                          // recommended values are between 30 and 70
                                          // 50 is "middle" 2.5 volt center
                                          // default value is 55
                                          // 100 = 5V (never use this high)
                                          // 0 = 0 V (never use this low
                                          

/////////////////////////
// MOUSE MOTION /////////
/////////////////////////
#define MOUSE_MOTION_UPDATE_INTERVAL  35   // how many loops to wait between 
                                           // sending mouse motion updates
                                           
#define PIXELS_PER_MOUSE_STEP         4     // a larger number will make the mouse
                                           // move faster

#define MOUSE_RAMP_SCALE              150  // Scaling factor for mouse movement ramping
                                           // Lower = more sensitive mouse movement
                                           // Higher = slower ramping of speed
                                           // 0 = Ramping off
                                            
#define MOUSE_MAX_PIXELS              10   // Max pixels per step for mouse movement

/*

///////////////////////////
// ADDITIONAL KEY CODES ///
///////////////////////////

- you can use these codes in the keyCodes array above
- to get modifier keys, function keys, etc 

KEY_LEFT_CTRL
KEY_LEFT_SHIFT		
KEY_LEFT_ALT		
KEY_LEFT_GUI		
KEY_RIGHT_CTRL		
KEY_RIGHT_SHIFT		
KEY_RIGHT_ALT	
KEY_RIGHT_GUI		

KEY_BACKSPACE		
KEY_TAB				
KEY_RETURN			
KEY_ESC				
KEY_INSERT			
KEY_DELETE			
KEY_PAGE_UP			
KEY_PAGE_DOWN		
KEY_HOME
KEY_END				
KEY_CAPS_LOCK	
	
KEY_F1				
KEY_F2				
KEY_F3				
KEY_F4				
KEY_F5				
KEY_F6				
KEY_F7				
KEY_F8				
KEY_F9				
KEY_F10
KEY_F11				
KEY_F12			

*/

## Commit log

2012-05-18 initial commit of design files
    [makey_makey-v11.brd, makey_makey-v11.sch]
2012-06-05 v1.2 of MaKey MaKey renamed files to remove version number
    [makey_makey-v11.brd, makey_makey.brd, makey_makey.sch]
2012-06-15 Adding panelized MaKey MaKey eagle files and its gerbers
    [makey_makey-panel-v12.GBL, makey_makey-panel-v12.GBO, makey_makey-panel-v12.GBP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]
2012-06-15 Ammending BOM a bit.
    [makey_makey-v12-BOM-shared.ods]
2012-08-14 Initial commit of code (1.4.1 - first live version) Initial commit of MaKey MaKey Arduino addon (hardware directory)
2012-08-28 Fixed problem with "click" LED lighting up whenever the "up" LED lights up.
    It appears there should only be one of the inputs set to HIGH for each
    display LED. With two set to HIGH, it caused another led to be lit at
    low power.
    [makey_makey.ino]
2013-09-03 Cleaning up repo structure
    [makey_makey-panel-v12.GBL, makey_makey-panel-v12.GBO, makey_makey-panel-v12.GBP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]
2013-12-05 QC Revision
    1.) Switch 0402 to 0603 footprints
    2.) Updated to wide PTC footprint
    3.) Added more bstop over lead banks on 32u4 IC for better AOI.
    [makey_makey.brd, makey_makey.sch]
2013-12-10 Swapped positions of PTC and C8
    Swapped the positions of PTC and C8 to better accommodate and center the
    "POWER" silk.
    [makey_makey.brd]
2014-01-09 Deleted old v12 panel. Created new v13 Giant Panel
    [makey_makey-panel-v12.GBL, makey_makey-panel-v12.GBO, makey_makey-panel-v12.GBP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]
2014-11-14 Fixed typo in makey_makey.ino
    [makey_makey.ino]
2015-08-12 Changing width of polygons from 0 to 0.001
    Polygons on bPlace, tPlace and top copper layers are affected.
    This makes generating gerber files from the board _much_ faster. Shouldn't
    have any visible effect on the appearance of the board.
    [makey_makey.brd, makey_makey.sch]
2015-08-12 Upping version to 1.4
    Removing old changelog from schematic's second sheet.
    [makey_makey.sch]
2015-08-27 Signed the Windows driver
2015-11-25 Updating boards adding platforms.txt for 1.6.6 compatibility
2016-01-21 Adding Arduino version check to Mouse and Keyboard h file includes

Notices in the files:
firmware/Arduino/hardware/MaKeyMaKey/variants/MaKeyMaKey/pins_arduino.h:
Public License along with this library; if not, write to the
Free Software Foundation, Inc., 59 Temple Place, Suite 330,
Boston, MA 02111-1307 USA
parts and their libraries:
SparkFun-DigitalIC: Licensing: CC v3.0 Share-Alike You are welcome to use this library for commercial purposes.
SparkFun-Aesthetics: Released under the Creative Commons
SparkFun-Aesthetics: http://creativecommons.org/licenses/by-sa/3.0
